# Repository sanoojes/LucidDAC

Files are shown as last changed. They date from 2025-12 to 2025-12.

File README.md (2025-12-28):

# LucidDAC

A USB-C to 3.5mm DAC cuzz new phones doesn't come with a 3.5mm Jack(f Apple for
removing so that the industry follows)

## PCB

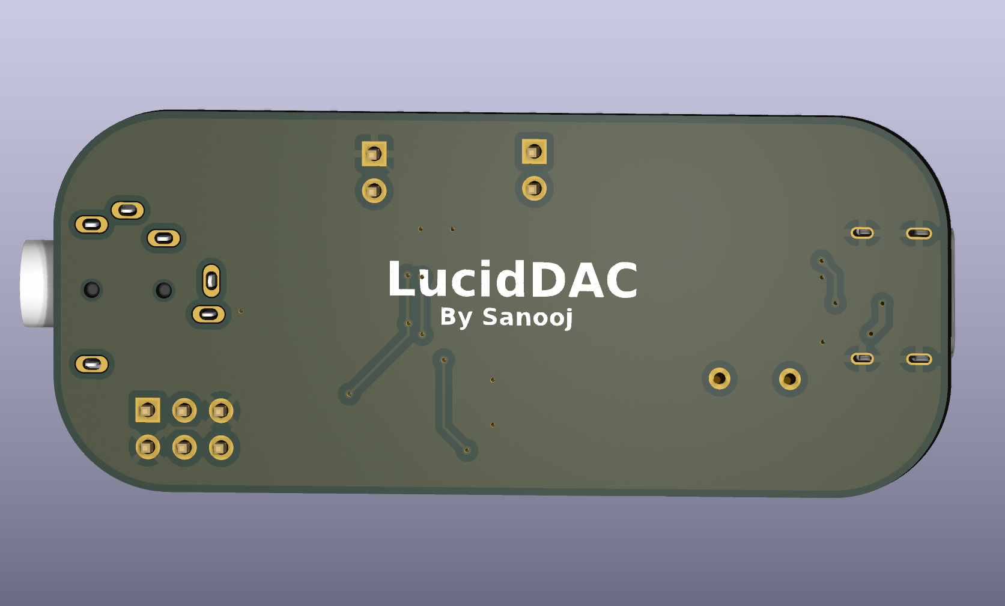
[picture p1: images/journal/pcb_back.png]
PCB Back

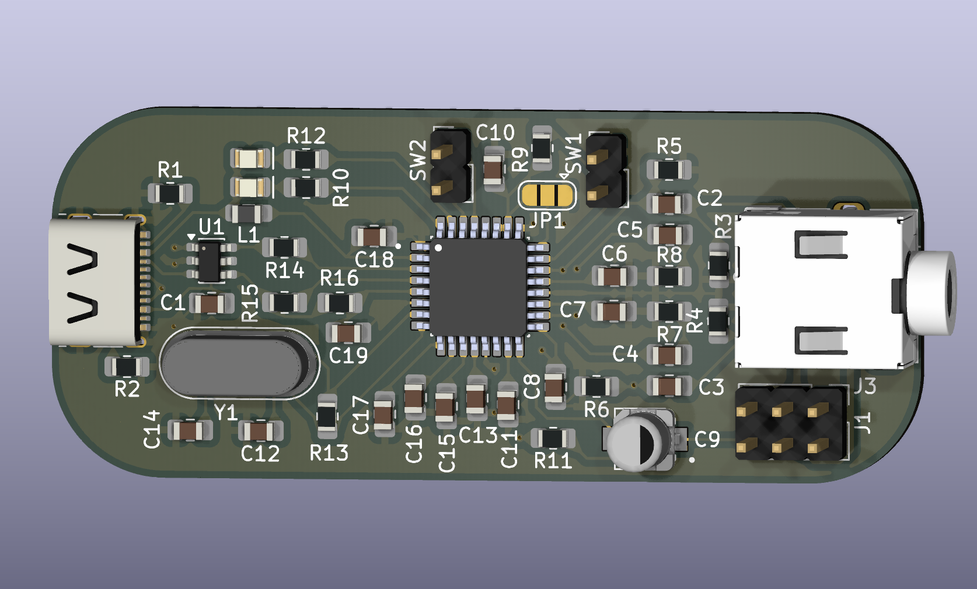
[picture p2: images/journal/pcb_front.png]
PCB Front

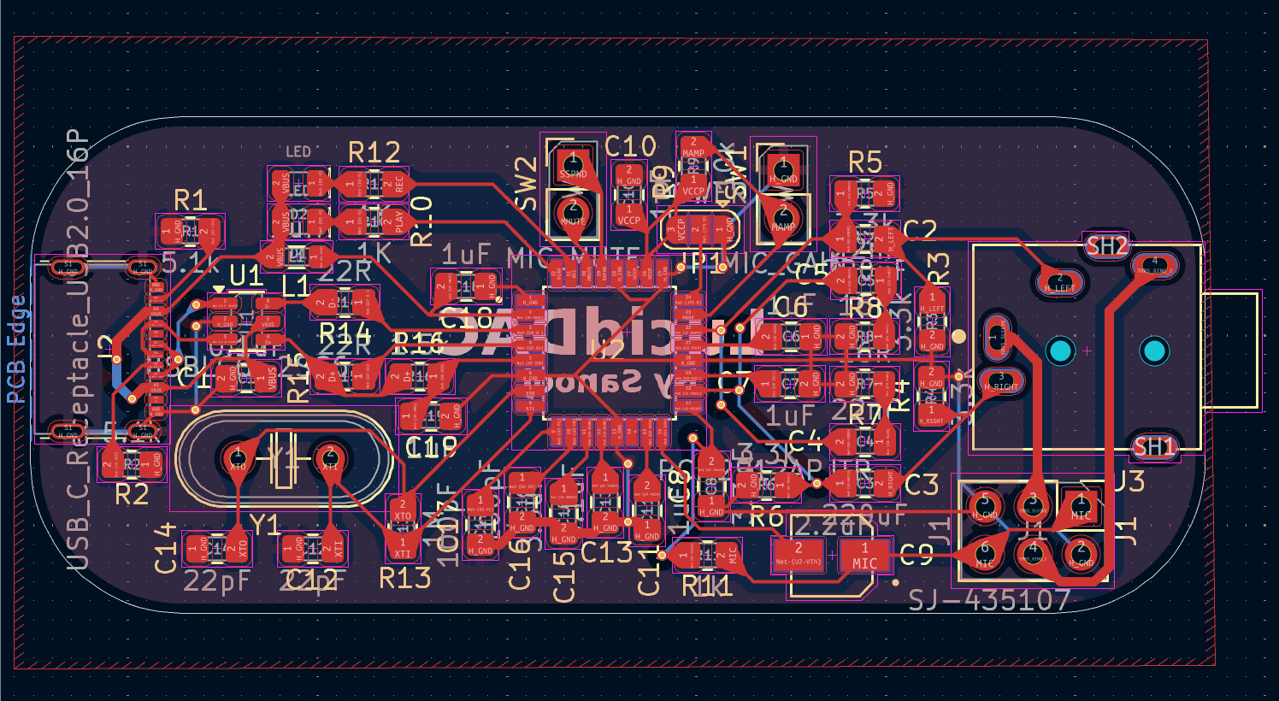
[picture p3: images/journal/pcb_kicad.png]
PCB KiCad

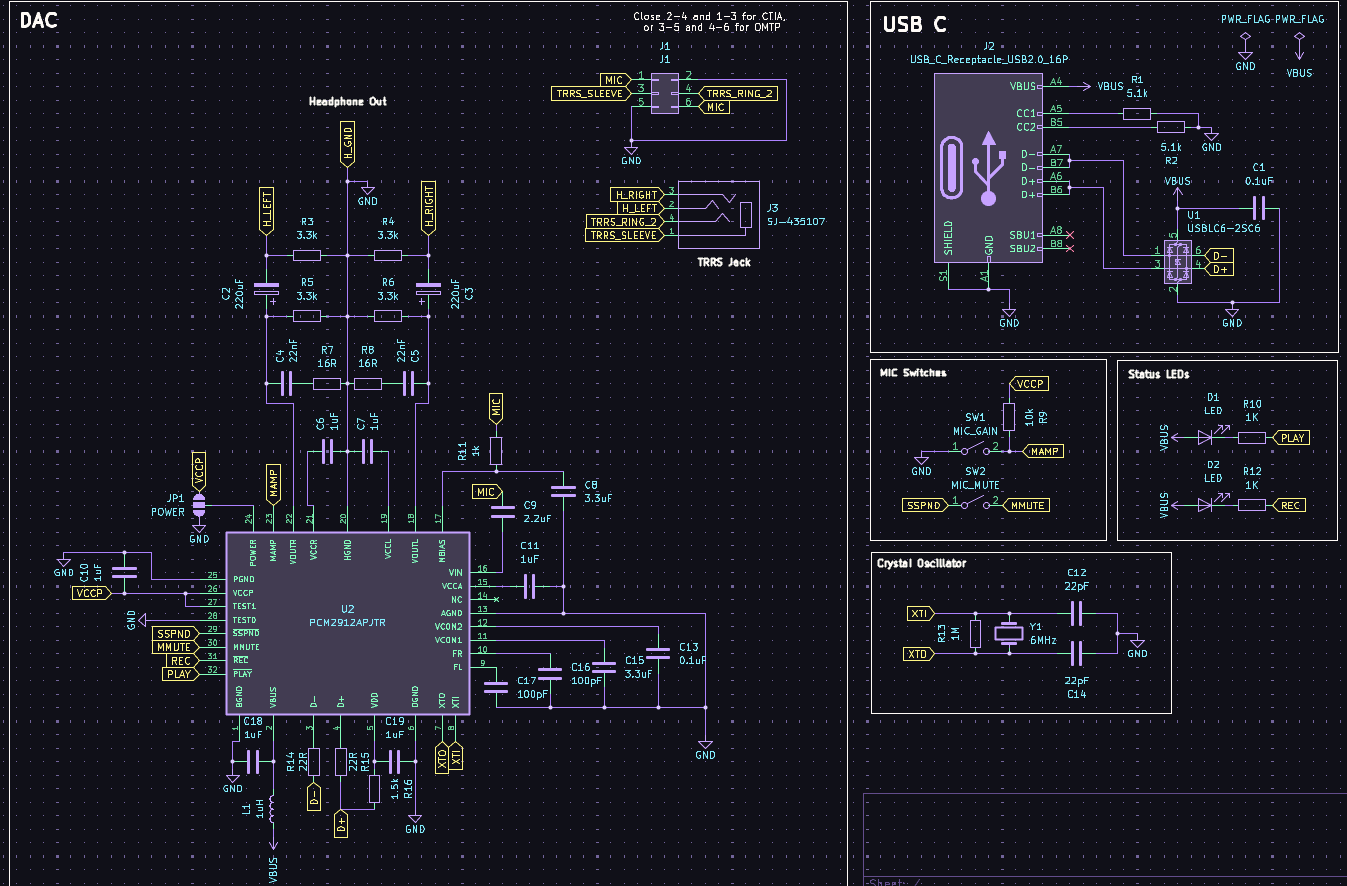
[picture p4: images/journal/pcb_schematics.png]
PCB Schematics


## Bill of Materials

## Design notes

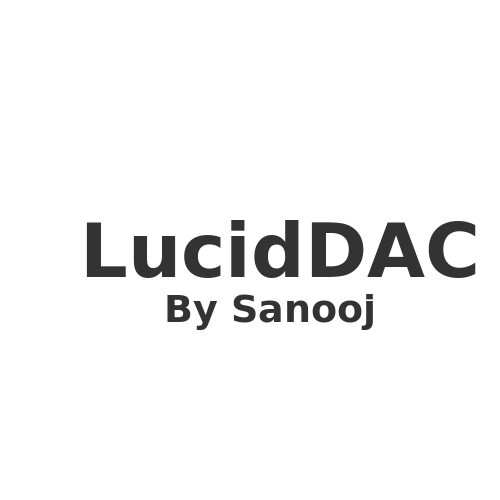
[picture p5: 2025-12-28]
images/pcb/name.png

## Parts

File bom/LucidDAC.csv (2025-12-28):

Item | Value | Description | Order Quantity | Unit Price | Total Price | URL
EEE-FK1A221XP | 220uF | Electrolytic Capacitor | 3 | ₹0.69 | ₹2.07 | https://www.digikey.in/en/products/detail/panasonic-electronic-components/EEE-FK1A221XP/765946
CL21B105KOFNFNE | 1uF | MLCC | 8 | ₹0.70 | ₹5.60 | https://robu.in/product/cl21b105kofnfne-samsang-16v-1uf-x7r-%c2%b110-0805-multilayer-ceramic-capacitors-mlcc-smd-smt-rohs/
CL21B104KAFNNNE | 0.1uF | MLCC | 4 | ₹0.70 | ₹2.80 | https://robu.in/product/cl21b104kafnnne-samsang-25v-100nf-x7r-%c2%b110-0805-multilayer-ceramic-capacitors-mlcc-smd-smt-rohs/
Robu 595604 | 22nF | MLCC | 3 | ₹2.16 | ₹6.48 | https://robu.in/product/22nf-0805-surface-mount-multilayer-ceramic-capacitor-pack-of-50/
CL21A335KPFNNNE | 3.3uF | MLCC | 3 | ₹6.00 | ₹18.00 | https://robu.in/product/cl21a335kpfnnne-samsang-10v-3-3uf-x5r-%c2%b110-0805-multilayer-ceramic-capacitors-mlcc-smd-smt-rohs/
Robu 595357 | 22pF | MLCC | 3 | ₹0.33 | ₹0.99 | https://robu.in/product/22pf-0805-surface-mount-multilayer-ceramic-capacitor-pack-of-50/
CL21C101JCANNNC | 100pF | MLCC | 3 | ₹0.37 | ₹1.11 | https://robu.in/product/cl21c101jcannnc-samsung-cap-ceramic-100pf-100v-c0g-5-pad-smd-0805-125c-t-r/
AC0805FR-073K3L | 3.3k | Resistor | 6 | ₹0.32 | ₹1.92 | https://robu.in/product/ac0805fr-073k3l-yageo-res-thick-film-0805-3-3k-ohm-1-0-125w1-8w-%c2%b1100ppm-c-pad-smd-t-r-automotive-aec-q200/
AC0805FR-071KL | 1K | Resistor | 4 | ₹0.72 | ₹2.88 | https://robu.in/product/ac0805fr-071kl-yageo-res-thick-film-0805-1k-ohm-1-0-125w1-8w-%c2%b1100ppm-c-pad-smd-t-r-automotive-aec-q200/
AF0805FR-075K1L | 5.1k | Resistor | 3 | ₹1.27 | ₹3.81 | https://robu.in/product/af0805fr-075k1l-yageo-5-1k%cf%89-%c2%b11-125mw-thick-film-%c2%b1100ppm-%e2%84%83-0805-chip-resistor-surface-mount-rohs/
RC0805FR-0716RL | 16R | Resistor | 3 | ₹0.42 | ₹1.26 | https://robu.in/product/rc0805fr-0716rl-yageo-smd-chip-resistor-16-ohm-%c2%b1-1-125-mw-0805-2012-metric-thick-film-general-purpose/
RC0805FR-0722RL | 22R | Resistor | 3 | ₹0.25 | ₹0.75 | https://robu.in/product/rc0805fr-0722rl-yageo-smd-chip-resistor-22-ohm-%c2%b1-1-125-mw-0805-2012-metric-thick-film-general-purpose/
RC0805FR-0710KL | 10k | Resistor | 2 | ₹0.35 | ₹0.70 | https://robu.in/product/rc0805fr-0710kl-yageo-res-thick-film-0805-10k-ohm-1-0-125w1-8w-%c2%b1100ppm-c-pad-smd-t-r/
RT0805FRE071ML | 1M | Resistor | 2 | ₹2.53 | ₹5.06 | https://robu.in/product/rt0805fre071ml-yageo-125mw-thin-film-resistor-%c2%b150ppm-%e2%84%83-%c2%b11-1m%cf%89-0805-chip-resistor-surface-mount-rohs/
AC0805FR-071K5L | 1.5k | Resistor | 2 | ₹0.32 | ₹0.64 | https://robu.in/product/ac0805fr-071k5l-yageo-res-thick-film-0805-1-5k-ohm-1-0-125w1-8w-%c2%b1100ppm-c-pad-smd-t-r-automotive-aec-q200/
MLP2012H1R0MT0S1 | 1uH | Inductor | 2 | ₹13.00 | ₹26.00 | https://robu.in/product/mlp2012h1r0mt0s1-tdk-1-1a-1uh-%C2%B120-120m%CF%89-0805-inductors-smd-rohs
LTST-C170GKT | Green LED | LED | 2 | ₹5.00 | ₹10.00 | https://robu.in/product/ltst-c170gkt-lite-on-20ma-6mcd-colorless-transparent-lens-55%e2%84%8385%e2%84%83-569nm-yellow-green-130-100mw-2-1v-0805-led-indication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
LTST-C171KRKT | Red LED | LED | 2 | ₹2.73 | ₹5.46 | https://robu.in/product/ltst-c171krkt-lite-on-20ma-54mcd-colorless-transparent-lens-55%e2%84%8385%e2%84%83-631nm-red-130-75mw-2v-0805-led-indication-discrete-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
EEE-HB1H2R2R | 2.2uF | Electrolytic Capacitor | 3 | ₹30.00 | ₹90.00 | https://www.digikey.in/en/products/detail/panasonic-electronic-components/EEE-HB1H2R2R/817516
Robu 1142271 | 6MHz | Crystal Oscillator | 2 | ₹12.00 | ₹24.00 | https://robu.in/product/6mhz-crystal-oscillator-hc49-us-package-pack-of-5/
Robu 537558 | Pin Header 01x02 (2) | Pin Headers | 1 | ₹10.00 | ₹10.00 | https://robu.in/product/2-54mm-2x40-pin-male-double-row-straight-long-header-strip/
Robu 535810 | Pin Header 02x06 | Pin Headers | 1 | ₹18.00 | ₹18.00 | https://robu.in/product/2-54mm-2x20-pin-male-double-row-smt-header-strip-pack-of-5/
TYPE-C-31-M-23 | USB_C_Receptacle | USB C Receptacle | 2 | ₹65.00 | ₹130.00 | https://robu.in/product/type-c-31-m-23-hroparts-1-surface-mount-right-angle-16p-female-55%e2%84%8385%e2%84%83-type-c-smd-usb-connectors-rohs/
USBLC6-2SC6 | USBLC6-2SC6 | Esd Protection | 2 | ₹31.00 | ₹62.00 | https://www.digikey.in/en/products/detail/stmicroelectronics/USBLC6-2SC6/1040559
PCM2912APJTR | PCM2912APJTR | AUDIO Codec | 2 | ₹971.00 | ₹1,942.00 | https://www.digikey.in/en/products/detail/texas-instruments/PCM2912APJTR/2047509
SJ-435107 | SJ-435107 | TRRS Jack | 2 | ₹145.00 | ₹290.00 | https://www.digikey.in/en/products/detail/same-sky-formerly-cui-devices/SJ-435107/3064634
Expected shipping | For DigiKey and Robu | DigiKey has 1200rs Shipping Fees |  |  | 2000
TOTAL |  |  |  |  | ₹4,661.53

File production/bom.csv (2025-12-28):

Designator | Footprint | Quantity | Value | LCSC Part #
C1, C13 | 0805 | 2 | 0.1uF
C10, C11, C18, C19, C6, C7 | 0805 | 6 | 1uF
C12, C14 | 0805 | 2 | 22pF
C15, C8 | 0805 | 2 | 3.3uF
C16, C17 | 0805 | 2 | 100pF
C4, C5 | 0805 | 2 | 22nF
C9 | CAP_EEEHB1H2R2R | 1 | 2.2uF
CE1, CE2 | CAP_EEEFK1A221XP | 2 | 220uF
D1, D2 | 0805 | 2 | LED
J1 | PinHeader_2x03_P2.54mm_Vertical | 1 | J1
J2 | USB_C_Receptacle_HRO_TYPE-C-31-M-23 | 1 | USB_C_Receptacle_USB2.0_16P
J3 | CUI_SJ-435107 | 1 | SJ-435107
JP1 | SolderJumper-3_P1.3mm_Open_RoundedPad1.0x1.5mm | 1 | POWER
L1 | 0805 | 1 | 1uH
MIC_GAIN | PinHeader_1x02_P2.54mm_Vertical | 1 | MIC_GAIN
MIC_MUTE | PinHeader_1x02_P2.54mm_Vertical | 1 | MIC_MUTE
R1, R2 | 0805 | 2 | 5.1k
R10, R11, R12 | 0805 | 3 | 1K
R13 | 0805 | 1 | 1M
R14, R15 | 0805 | 2 | 22R
R16 | 0805 | 1 | 1.5k
R3, R4, R5, R6 | 0805 | 4 | 3.3k
R7, R8 | 0805 | 2 | 16R
R9 | 0805 | 1 | 10k
U1 | SOT-23-6 | 1 | USBLC6-2SC6
U2 | QFP80P900X900X120-32N | 1 | PCM2912APJTR
Y1 | Crystal_HC49-4H_Vertical | 1 | 6MHz

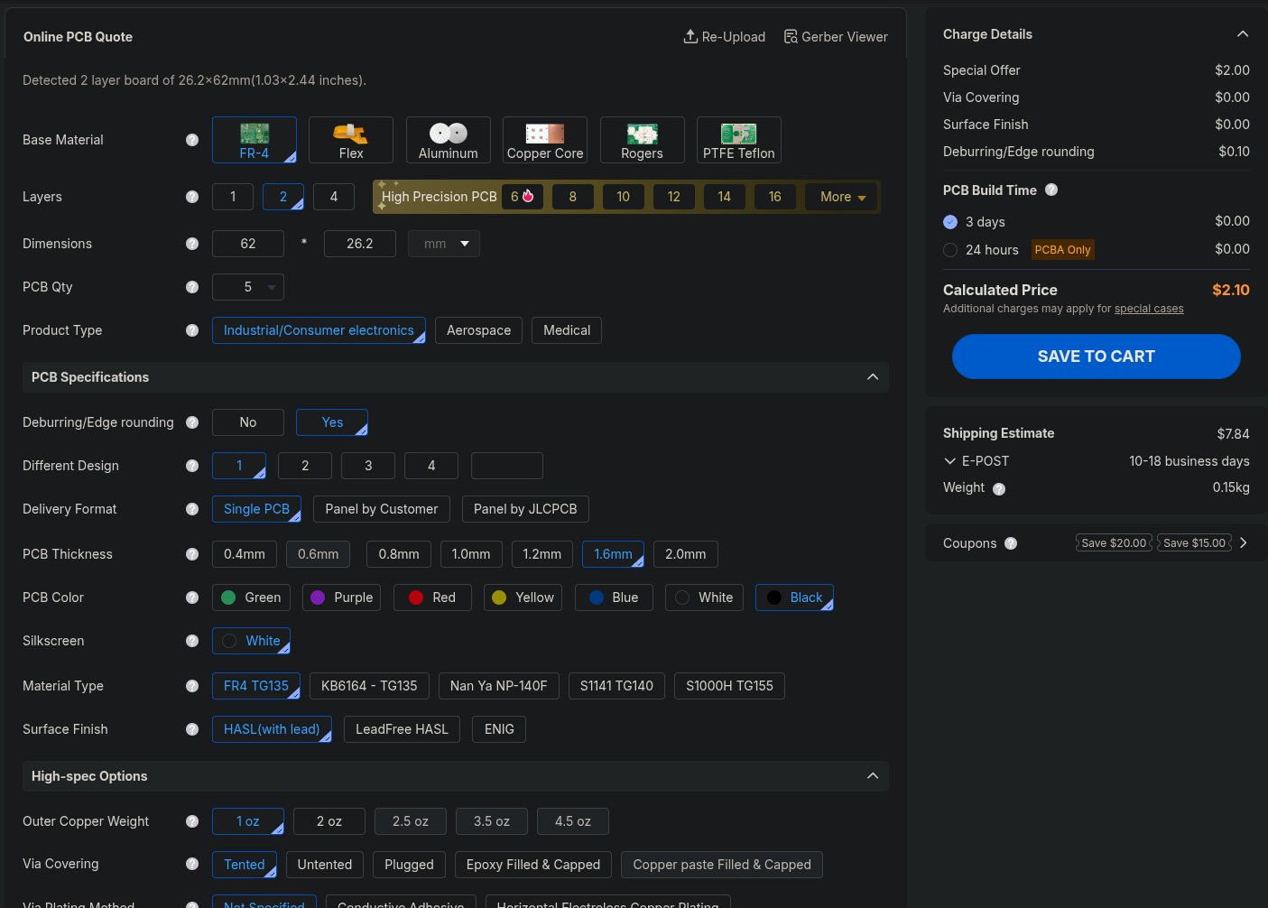
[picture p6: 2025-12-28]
images/bom/jlc.png

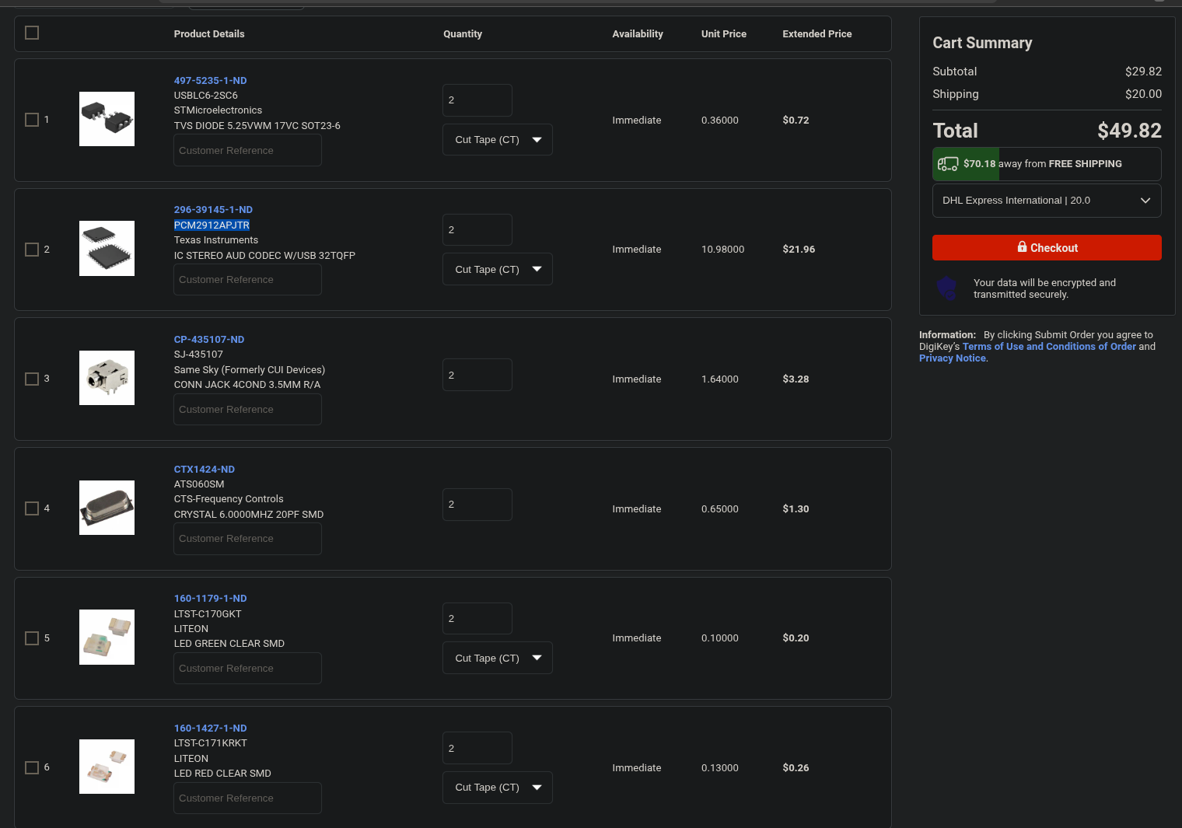
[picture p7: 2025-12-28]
images/bom/digikey.png

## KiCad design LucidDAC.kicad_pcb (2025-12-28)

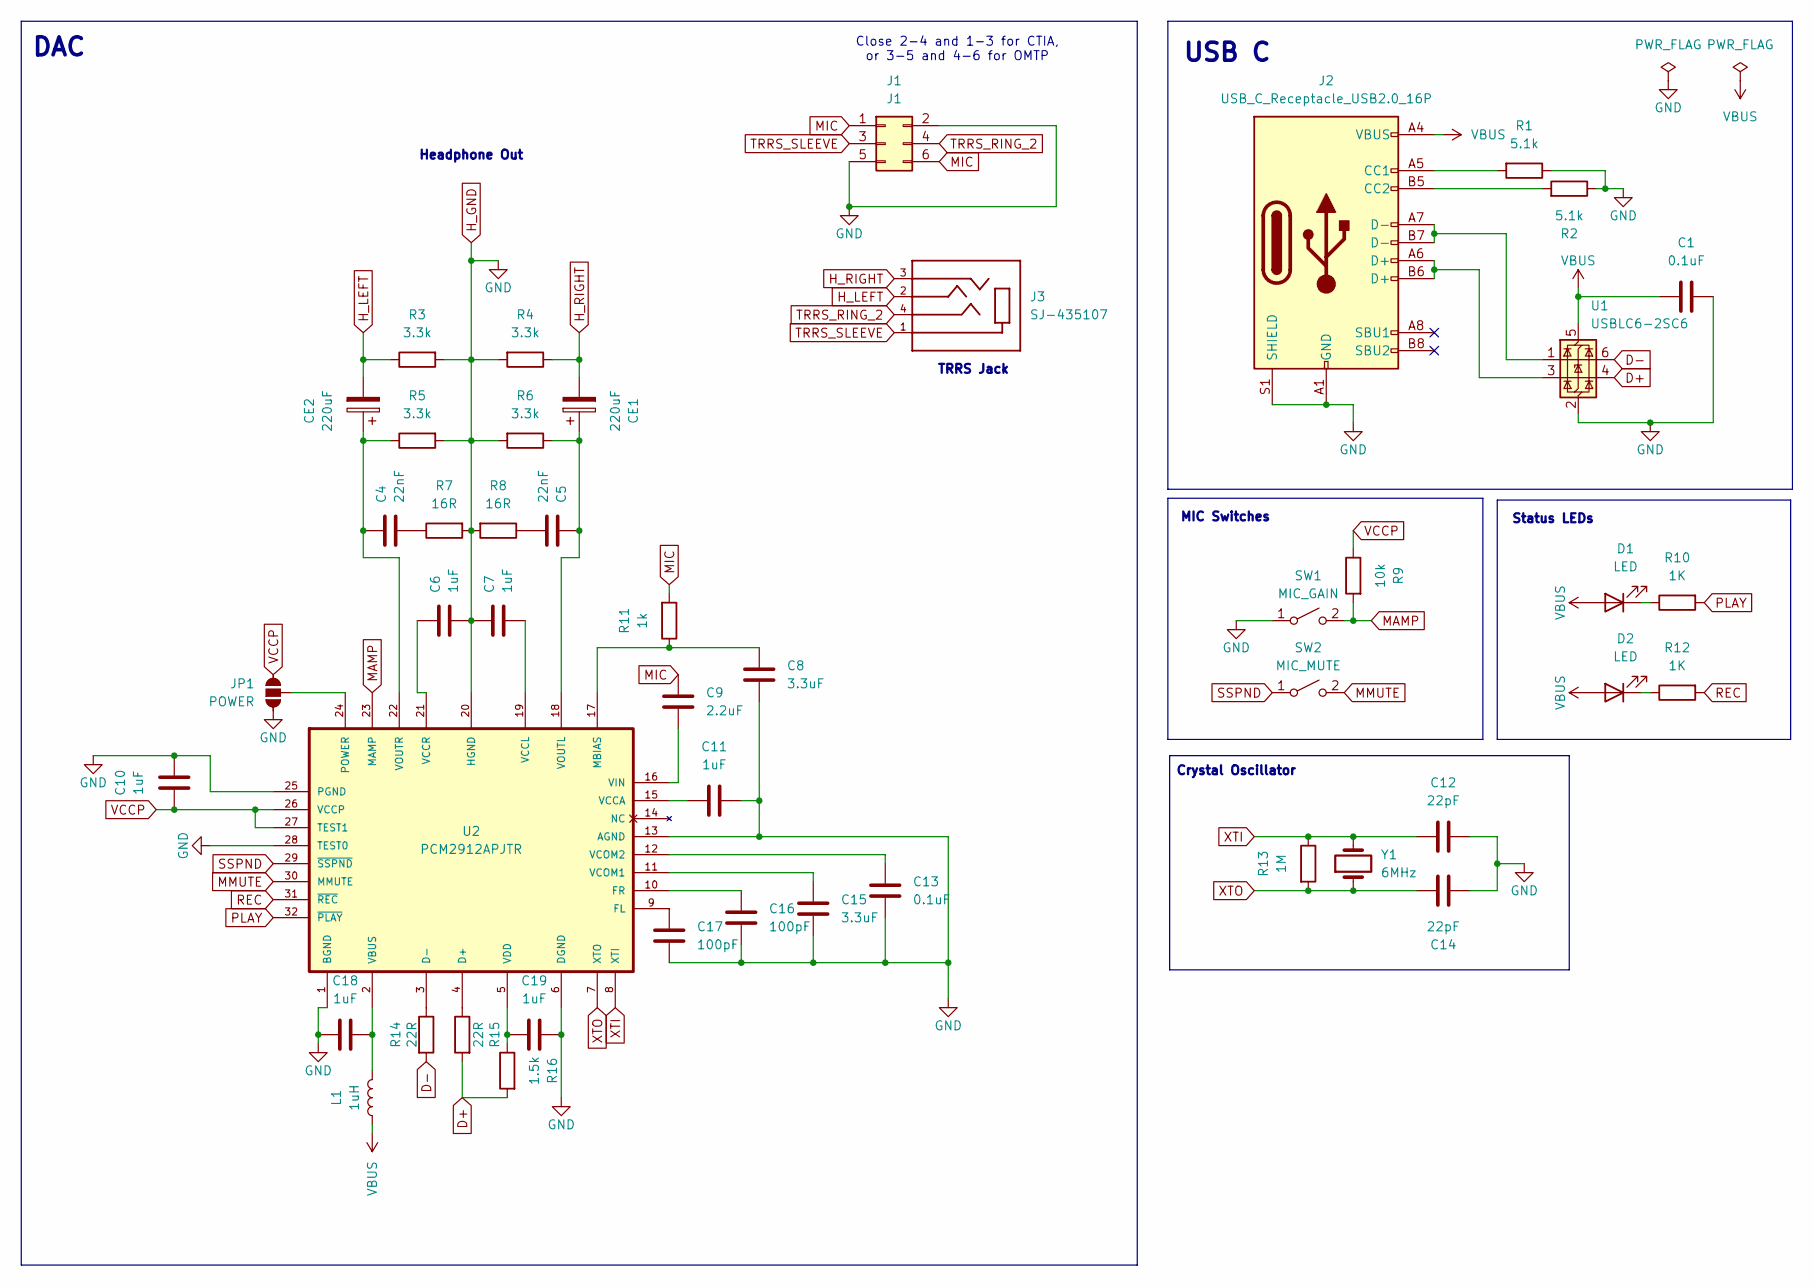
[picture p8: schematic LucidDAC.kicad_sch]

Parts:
C1, C13: 0.1uF; C_0805_2012Metric_Pad1.18x1.45mm_HandSolder
C4, C5: 22nF; C_0805_2012Metric_Pad1.18x1.45mm_HandSolder
C6, C7, C10, C11, C18, C19: 1uF; C_0805_2012Metric_Pad1.18x1.45mm_HandSolder
C8, C15: 3.3uF; C_0805_2012Metric_Pad1.18x1.45mm_HandSolder
C9: 2.2uF; CAP_EEEHB1H2R2R
C12, C14: 22pF; C_0805_2012Metric_Pad1.18x1.45mm_HandSolder
C16, C17: 100pF; C_0805_2012Metric_Pad1.18x1.45mm_HandSolder
CE1, CE2: 220uF; CAP_EEEFK1A221XP
D1, D2: LED; LED_0805_2012Metric
J1: J1; PinHeader_2x03_P2.54mm_Vertical
J2: USB_C_Receptacle_USB2.0_16P; USB_C_Receptacle_HRO_TYPE-C-31-M-23
J3: SJ-435107; CUI_SJ-435107
JP1: POWER; SolderJumper-3_P1.3mm_Open_RoundedPad1.0x1.5mm
L1: 1uH; L_0805_2012Metric_Pad1.05x1.20mm_HandSolder
R1, R2: 5.1k; R_0805_2012Metric_Pad1.20x1.40mm_HandSolder
R3, R4, R5, R6: 3.3k; R_0805_2012Metric_Pad1.20x1.40mm_HandSolder
R7, R8: 16R; R_0805_2012Metric_Pad1.20x1.40mm_HandSolder
R9: 10k; R_0805_2012Metric_Pad1.20x1.40mm_HandSolder
R10, R12: 1K; R_0805_2012Metric_Pad1.20x1.40mm_HandSolder
R11: 1k; R_0805_2012Metric_Pad1.20x1.40mm_HandSolder
R13: 1M; R_0805_2012Metric_Pad1.20x1.40mm_HandSolder
R14, R15: 22R; R_0805_2012Metric_Pad1.20x1.40mm_HandSolder
R16: 1.5k; R_0805_2012Metric_Pad1.20x1.40mm_HandSolder
SW1: MIC_GAIN; PinHeader_1x02_P2.54mm_Vertical
SW2: MIC_MUTE; PinHeader_1x02_P2.54mm_Vertical
U1: USBLC6-2SC6; SOT-23-6
U2: PCM2912APJTR; QFP80P900X900X120-32N
Y1: 6MHz; Crystal_HC49-4H_Vertical

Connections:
D+: R15.2, R16.2, U1.4 (I/O2)
D-: R14.2, U1.6 (I/O1)
H_GND: C1.2, C6.1, C7.2, C8.1, C10.2, C11.1, C12.1, C13.2, C14.1, C15.2, C16.2, C17.2, C18.1, C19.2, J1.2, J1.5, J2.A1 (GND), J2.A12 (GND), J2.B1 (GND), J2.B12 (GND), J2.S1 (SHIELD), JP1.1 (A), R1.1, R2.1, R3.2, R4.2, R5.2, R6.2, R7.2, R8.2, SW1.1 (A), U1.2 (GND), U2.1 (BGND), U2.6 (DGND), U2.13 (AGND), U2.20 (HGND), U2.25 (PGND), U2.28 (TEST0); also elsewhere on the board
H_LEFT: CE2.2, J3.2, R3.1
H_RIGHT: CE1.2, J3.3, R4.1
MAMP: R9.2, SW1.2 (B), U2.23 (MAMP); also elsewhere on the board
MIC: C9.1, J1.1, J1.6, R11.2
MMUTE: SW2.2 (B), U2.30 (MMUTE); also elsewhere on the board
unnamed: C4.1, R7.1
unnamed: C5.1, R8.1
unnamed: D1.1 (K), R10.1
unnamed: D2.1 (K), R12.1
unnamed: J2.A5 (CC1), R1.2
unnamed: J2.B5 (CC2), R2.2
unnamed: J2.A6 (D+), J2.B6 (D+), U1.3 (I/O2)
unnamed: J2.A7 (D-), J2.B7 (D-), U1.1 (I/O1)
unnamed: JP1.2 (B), U2.24 (POWER)
unnamed: R15.1, U2.4 (D+)
unnamed: R14.1, U2.3 (D-)
unnamed: C17.1, U2.9 (FL)
unnamed: C16.1, U2.10 (FR)
unnamed: C8.2, R11.1, U2.17 (MBIAS)
unnamed: C18.2, L1.1, U2.2 (VBUS)
unnamed: C11.2, U2.15 (VCCA)
unnamed: C7.1, U2.19 (VCCL)
unnamed: C6.2, U2.21 (VCCR)
unnamed: C15.1, U2.11 (VCOM1)
unnamed: C13.1, U2.12 (VCOM2)
unnamed: C19.1, R16.1, U2.5 (VDD)
unnamed: C9.2, U2.16 (VIN)
unnamed: C5.2, CE1.1, R6.1, U2.18 (VOUTL)
unnamed: C4.2, CE2.1, R5.1, U2.22 (VOUTR)
PLAY: R10.2, U2.32 (~PLAY)
REC: R12.2, U2.31 (~REC)
SSPND: SW2.1 (A), U2.29 (~SSPND); also elsewhere on the board
TRRS_RING_2: J1.4, J3.4
TRRS_SLEEVE: J1.3, J3.1
VBUS: C1.1, D1.2 (A), D2.2 (A), J2.A4 (VBUS), J2.A9 (VBUS), J2.B4 (VBUS), J2.B9 (VBUS), L1.2, U1.5 (VBUS)
VCCP: C10.1, JP1.3 (C), R9.1, U2.26 (VCCP), U2.27 (TEST1)
XTI: C12.2, R13.1, U2.8 (XTI), Y1.2
XTO: C14.2, R13.2, U2.7 (XTO), Y1.1

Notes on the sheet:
Headphone Out
USB C
Close 2-4 and 1-3 for CTIA, or 3-5 and 4-6 for OMTP
Status LEDs
Crystal Oscillator
DAC
TRRS Jack
MIC Switches

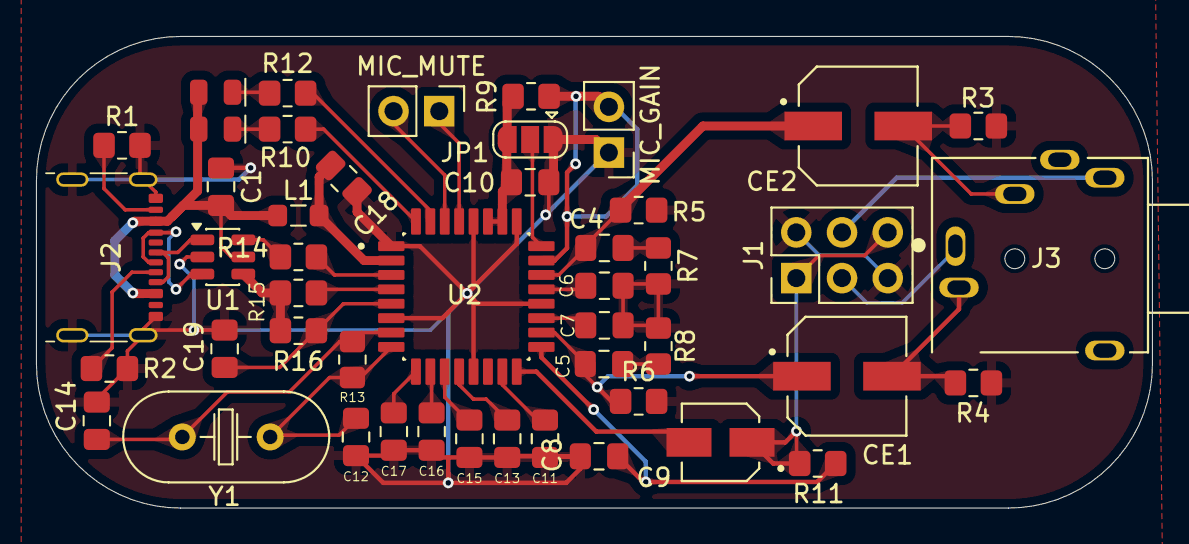
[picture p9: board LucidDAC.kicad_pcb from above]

Board: 2 copper layers, 62.0 x 26.2 mm, 48 parts (1 on the bottom side), 41 nets.

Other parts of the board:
MIC_GAIN: MIC_GAIN; PinHeader_1x02_P2.54mm_Vertical
MIC_MUTE: MIC_MUTE; PinHeader_1x02_P2.54mm_Vertical
ref: LOGO

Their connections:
H_GND: MIC_GAIN.1 (A); also elsewhere on the board
MAMP: MIC_GAIN.2 (B); also elsewhere on the board
MMUTE: MIC_MUTE.2 (B); also elsewhere on the board
SSPND: MIC_MUTE.1 (A); also elsewhere on the board

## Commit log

2025-12-28 init: initial commit
    [LucidDAC-bak.kicad_sch, LucidDAC.kicad_pcb, LucidDAC.kicad_sch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]
2025-12-28 add bom.csv
    [LucidDAC.csv]
2025-12-28 update bom
    [LucidDAC.csv]
2025-12-28 update pcb
    [LucidDAC.kicad_pcb, LucidDAC.kicad_sch, bom.csv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]
2025-12-28 fix: bom total value
    [LucidDAC.csv]
